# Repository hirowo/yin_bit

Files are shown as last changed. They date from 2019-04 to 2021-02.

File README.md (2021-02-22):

# yin:bit
micro:bit用の拡張モジュールです。micro:bitでフルカラーLED(WS2812B)をコントロールできます。

## 特長
従来からmicro:bitでフルカラーLEDを点灯させるモジュール等はありましたが、  micro:bitから出力される3.3VをフルカラーLEDの電源として使っているものや、電源を単3電池×3本を前提にしている物が多く、安定して光らせられるLEDの数は多くはありませんでした。

本モジュールは、本モジュールについているUSBコネクタから電源供給することで、  micro:bitに給電しつつフルカラーLEDを5V給電することが可能で、micro:bitからフルカラーLEDに給電する際より多くの数のLEDを安定して光らせることができます。

フルカラーLEDの点灯を一時的に抑えたいとき等のために、フルカラーLEDの電源ON/OFFスイッチも実装してあります。

Groveコネクタも実装してありますので、センサの値に応じて好きな色に光らせるといったこともできます。

## 説明動画
(http://www.youtube.com/watch?v=7cNPFFAmlIE "yin:bit紹介動画")

## Ver2.0の特徴
光らせたいけどはんだ付けは敷居が高い…という声があり、フルカラーLED部分がGrove互換コネクタが付き、はんだ付け無しでyin:bitを扱えるようになりました。

下記のようなGrove互換コネクタ付きフルカラーLEDを使えます。
 - [Grove - RGB LED (WS2813 Mini)](https://www.seeedstudio.com/Grove-RGB-LED-WS2813-Mini-p-4269.html)
 - [Grove - RGB LED Ring (24-WS2813 Mini)](https://www.seeedstudio.com/Grove-RGB-LED-Ring-24-WS2813-Mini-p-4202.html)
 - [Grove - RGB LED Stick (20-WS2813 Mini)](https://www.seeedstudio.com/Grove-RGB-LED-Stick-20-WS2813-Mini-p-4271.html)
 - [HEX RGB LED Board (SK6812)](https://m5stack.com/products/hex-rgb-led-board-sk6812)
 - [SK6812 RGB LED Flex-strip](https://m5stack.com/collections/m5-unit/products/sk6812-rgb-led-flex-strip)

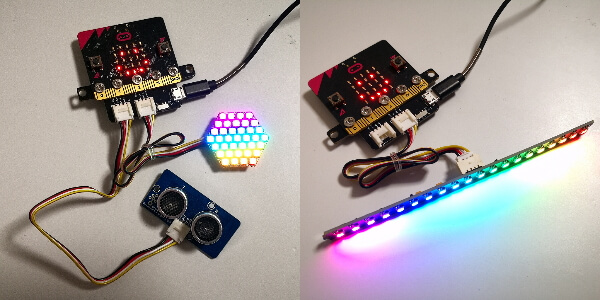
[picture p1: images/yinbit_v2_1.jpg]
v2.0_変更点1


またいろんなものに組み込むための固定用ネジ穴が追加されました。固定用ネジ穴部を分離するとyin:bitと同サイズになります。

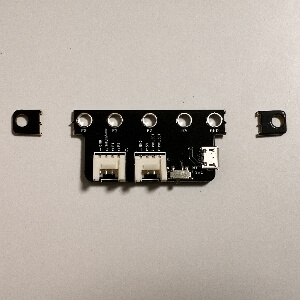
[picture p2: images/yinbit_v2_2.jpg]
v2.0_変更点2


## 使い方

1. yin:bitをmicro:bitにネジで固定します。

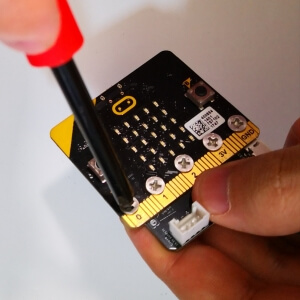
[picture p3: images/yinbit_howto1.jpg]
howto1


2. micro:bitにUSBケーブルを接続します。(プログラムをアプリから無線で書き込む際は不要)

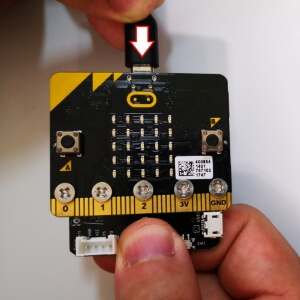
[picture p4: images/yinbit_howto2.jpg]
howto2


3. micro:bitにプログラムを書き込みます。(プログラムの例は[サンプル](#サンプル)参照)

4. yin:bitにUSBケーブルを差し込み電源と接続します。

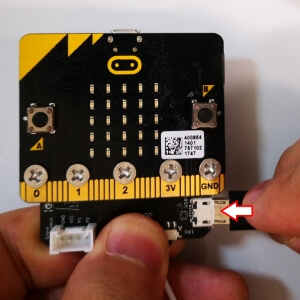
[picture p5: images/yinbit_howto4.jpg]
howto4


5. yin:bitのLED電源スイッチをONします。

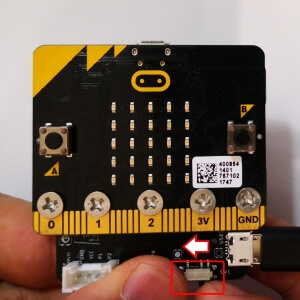
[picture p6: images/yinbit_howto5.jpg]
howto5


## スペック
 - サイズ(v1) : 50.8 × 22.0 × 6.5mm  
 - サイズ(v2) : 68.8 × 24.8 × 8.0mm
 - フルカラーLED用電源電圧(v2だとフルカラーLED用Grove互換コネクタ電源電圧) : 5V
 - フルカラーLED用電源最大電流値 : 2A
 - 入出力用Grove互換コネクタ電源電圧：3.3 V

## ピン
 - フルカラーLEDシリアルピン(v2だとフルカラーLED用Grove互換コネクタ) : P0 
 - 入出力用Grove互換コネクタ : P1/P2

## どこで買える？
 - [スイッチサイエンス](https://www.switch-science.com/catalog/5431/)
 - [スイッチサイエンス(コネクタ実装版)](https://www.switch-science.com/catalog/5821/)
 - [マルツオンライン](https://www.marutsu.co.jp/pc/i/1559574/)
 - [シリコンハウス共立](http://blog.siliconhouse.jp/archives/52170700.html)
 - [Shigezone](https://twitter.com/ShigezoneAkiba/status/1170178701419405312)
 
## サンプル

20個のLEDをついたフルカラーLEDテープを使うことを想定します。

micro:bitでフルカラーLEDを使う場合は「拡張機能」の「NeoPixel」をプロジェクトに追加してください。

### LEDを全て赤色に光らせる

[プログラム例](https://makecode.microbit.org/_FkpHuT0tiH0w)

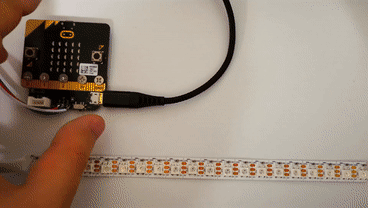
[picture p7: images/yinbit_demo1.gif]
demo1


### LEDを虹色に光らせて流す

[プログラム例](https://makecode.microbit.org/_2kAJboFzL6Ek)

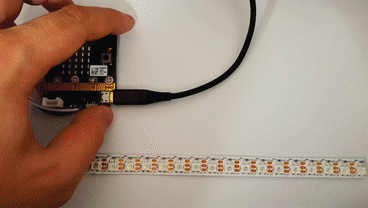
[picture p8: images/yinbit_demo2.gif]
demo2


### [Groveのジョイスティック](http://wiki.seeedstudio.com/Grove-Thumb_Joystick/)を使って操作する

[プログラム例](https://makecode.microbit.org/_hW461R9WmUEq)

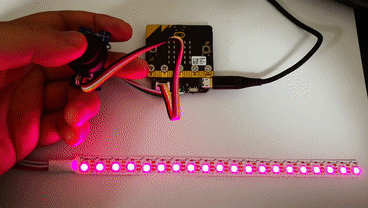
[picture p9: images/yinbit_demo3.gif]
demo3


### 無線を使って遠隔で電飾を操作する

[プログラム例](https://makecode.microbit.org/_WzrJAp9o9Hsq)

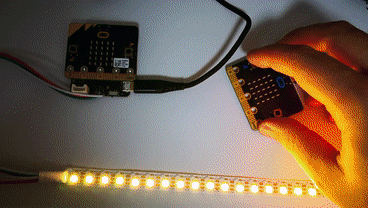
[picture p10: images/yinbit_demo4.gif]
demo4


### [Groveの超音波距離センサ](http://wiki.seeedstudio.com/Grove-Ultrasonic_Ranger/)を使って操作する

[プログラム例](https://makecode.microbit.org/_3hC7kxe1rCEK)

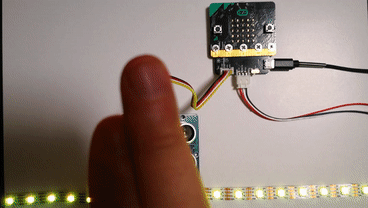
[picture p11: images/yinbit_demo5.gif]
demo5


### おまけ:サーボモーターを動かす

サーボモーターにも使えます。サーボモーターのコードとyin:bitを下記のように繋いでください。

|サーボモーター|yin:bit|
|:---:|:---:|
|茶色|GND|
|赤色|5V|
|黄色|LED_P0|

[プログラム例](https://makecode.microbit.org/_HUk0EjgW45yJ)

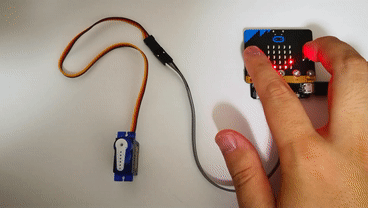
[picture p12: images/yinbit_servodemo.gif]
demo_servo


## 作品例

### [電飾エプロン](https://twitter.com/GomiHgy/status/1124863205099036674)(by[五味](https://twitter.com/GomiHgy))
電飾エプロン (https://twitter.com/GomiHgy/status/1124863205099036674)

### [micro:bitで光るスカート作ったで](https://www.nicovideo.jp/watch/sm35141886)(by[ましぐれ](https://twitter.com/mashigure))
micro:bitで光るスカート作ったで (https://www.nicovideo.jp/watch/sm35141886)

### [サイバリアン電飾](https://twitter.com/i/moments/1194228358986383362)(by[RealizePlus](https://twitter.com/Realize_Plus))
サイバリアン電飾 (https://twitter.com/i/moments/1194228358986383362)

### [光るウエディングドレスと連動する電飾キャンドルサービスを作ってみた](https://youtu.be/PWPQaGGIQgU)(by[静丘](https://twitter.com/Siz_oka))
光るウエディングドレスと連動する電飾キャンドルサービスを作ってみた (https://youtu.be/PWPQaGGIQgU)

## 終わりに

yin:bitの改良点がありましたら、ぜひIsuuesに書いてください。
こんな作品作ったよ！という方は [#yinbit](https://twitter.com/search?q=%23yinbit&src=typed_query) を付けてSNSなどで公開してくださると嬉しいです。
よい電飾ライフを！

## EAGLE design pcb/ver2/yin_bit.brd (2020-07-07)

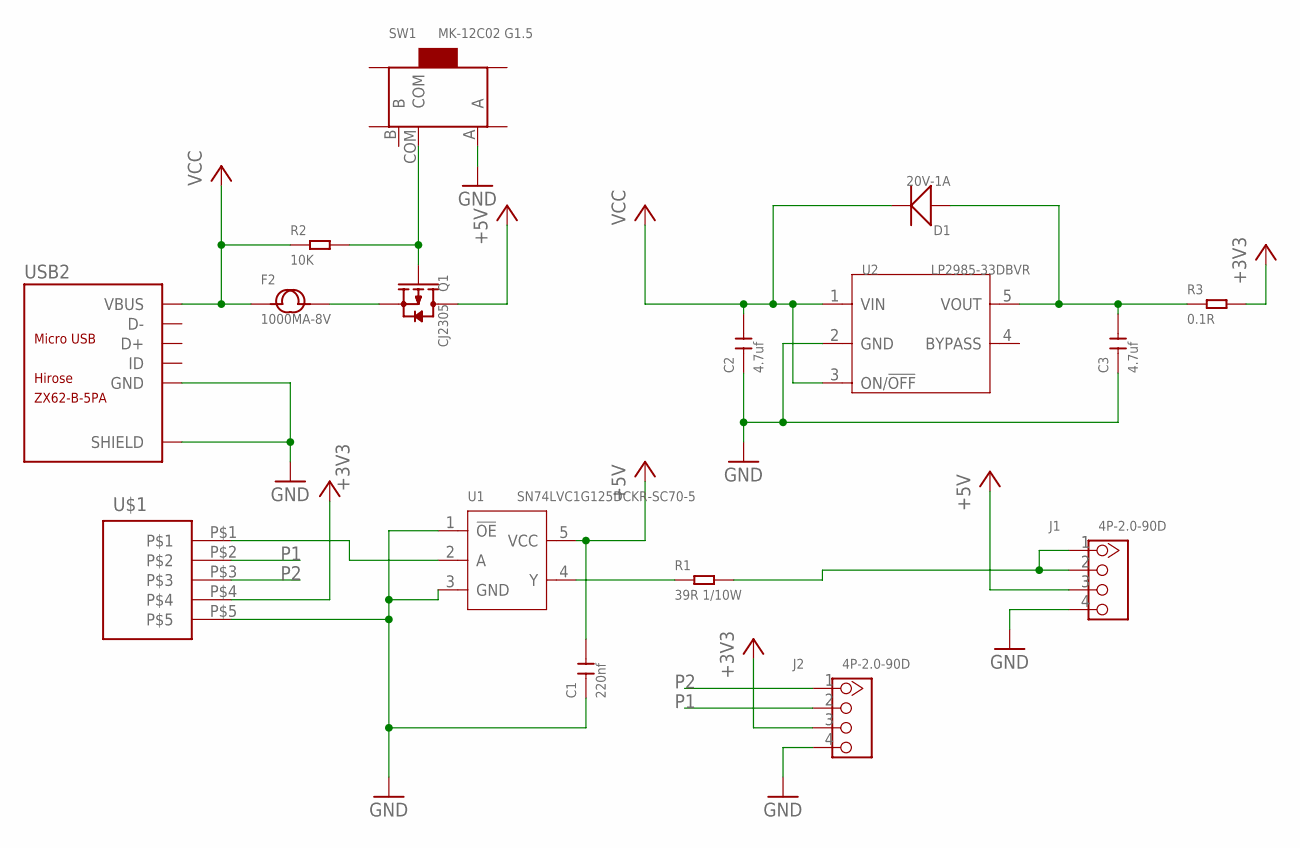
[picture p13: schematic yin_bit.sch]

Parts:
C1: 220nf; C0603
C2, C3: 4.7uf; C0603
D1: 20V-1A; SOD-123
F2: 1000MA-8V; F1206
J1, J2: 4P-2.0-90D; HW4-2.0-90D
Q1: CJ2305; SOT-23
R1: 39R 1/10W; R0603
R2: 10K; R0603
R3: 0.1R; R0805
SW1: MK-12C02 G1.5; SW7-SMD-L6.7X2.7X3.2MM
U1: SN74LVC1G125DCKR-SC70-5; SC-70-5
U2: LP2985-33DBVR; SOT-23-5
U$1: MICROBIT-HOLL
USB2: ZX62-B-5PA; MICRO-USB5+6P-SMD-0.65-AB

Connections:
+3V3: J2.3, R3.2, U$1.P$4
+5V: C1.2, J1.3, Q1.3 (D), U1.5 (VCC)
GND: C1.1, C2.1, C3.1, J1.4, J2.4, SW1.A, U1.1 (!OE!), U1.3 (GND), U2.2 (GND), U$1.P$5, USB2.5 (GND), USB2.P1 (SHIELD), USB2.P2 (SHIELD), USB2.P3 (SHIELD), USB2.P4 (SHIELD), USB2.P5 (SHIELD), USB2.P6 (SHIELD)
unnamed: U1.2 (A), U$1.P$1
unnamed: R1.1, U1.4 (Y)
unnamed: J1.1, J1.2, R1.2
unnamed: Q1.1 (G), R2.2, SW1.COM
unnamed: F2.2, Q1.2 (S)
unnamed: C3.2, D1.+, R3.1, U2.5 (VOUT)
P1: J2.2, U$1.P$2
P2: J2.1, U$1.P$3
VCC: C2.2, D1.-, F2.1, R2.1, U2.1 (VIN), U2.3 (ON/!OFF), USB2.1 (VBUS)

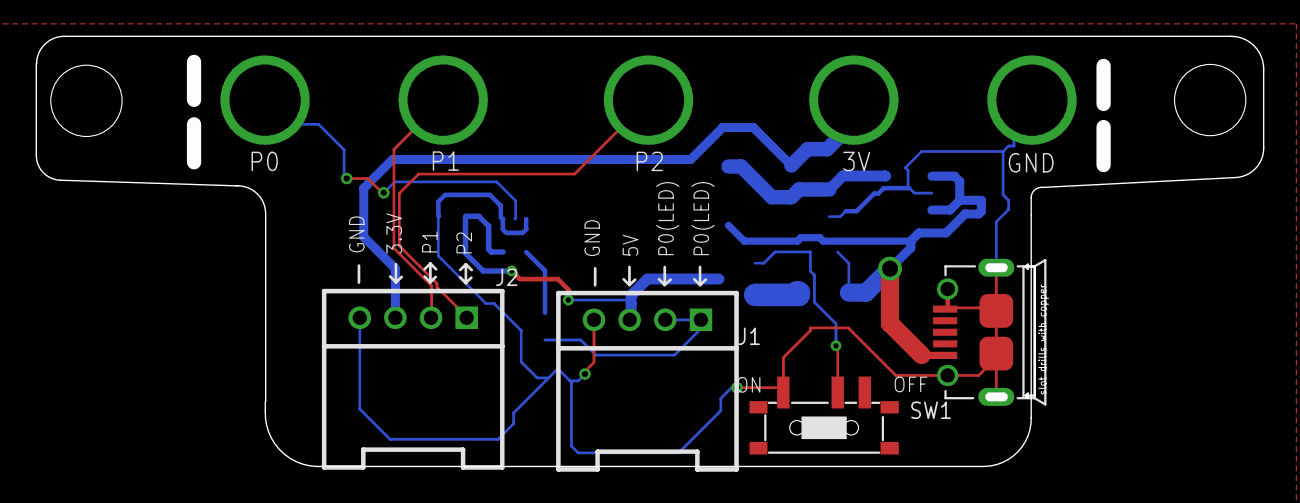
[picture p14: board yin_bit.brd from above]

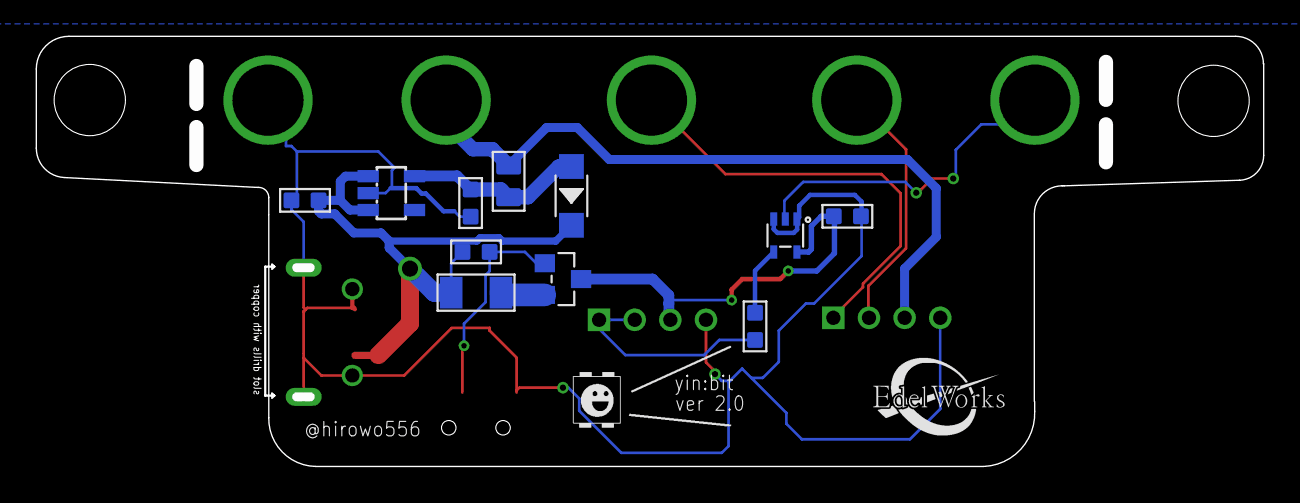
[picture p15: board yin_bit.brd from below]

Board: 2 copper layers, 68.9 x 24.1 mm, 16 parts (11 on the bottom side), 12 nets.

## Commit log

2019-01-18 Readmeの説明を追加
2019-01-18 回路データをアップデート
    [yin_bit.brd, yin_bit.sch]
2019-03-12 READMEの説明を更新
2019-03-12 GIF動画が表示されない問題の改善
2019-03-12 GIF動画を軽量化
2019-03-12 使い方説明用画像を追加
2019-03-12 README.md使い方の説明に画像を追加
2019-04-13 基板サイズ修正
    基板サイズを修正、USBの干渉問題
    [yin_bit.brd, yin_bit.sch]
2019-04-21 サーボモーターの動作例の追加
2019-05-22 使っていただいた作品を追加
    「micro:bitで光るスカート作ったで」を追加
2019-11-12 サイバリアン電飾を追加
2019-11-12 サイバリアン電飾の画像にリンク追加
2019-12-05 電飾エプロンを作品例に追加
2019-12-05 フルカラーLED用電源最大電流値の記述を追加
2019-12-06 距離センサデモ動画の追加
2019-12-06 Groveの超音波距離センサを使って操作するを追加及び説明微調整
2020-01-10 クリスマスツリーをつくろうを追加
2020-02-19 どこで買える？を追加
2020-07-02 基板関連データをPCBディレクトリに移動
    [yin_bit.brd, yin_bit.sch]
2020-07-07 ver2に回路データをアップ
    ver2に回路データをアップ
    [yin_bit.brd, yin_bit.sch]
2020-07-08 ver2.0用画像ファイルを追加
2020-07-08 v2.0の説明を追加
2020-07-08 #yinbitのリンクを追加
2020-07-08 レイアウト修正
2020-09-29 光るウエディングドレスと連動する電飾キャンドルサービスを作ってみたを追加
2021-02-22 説明動画を追加
